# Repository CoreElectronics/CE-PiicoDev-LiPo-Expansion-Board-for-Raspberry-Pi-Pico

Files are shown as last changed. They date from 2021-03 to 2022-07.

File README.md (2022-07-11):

# PiicoDev® LiPo Expansion Board for Raspberry Pi Pico

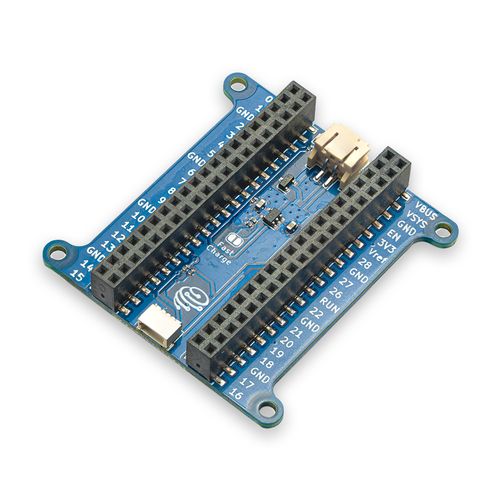
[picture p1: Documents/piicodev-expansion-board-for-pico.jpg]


The [PiicoDev® LiPo Expansion Board for Raspberry Pi Pico](https://core-electronics.com.au/catalog/product/view/sku/CE07693) is a great way to start experimenting with Raspberry Pi Pico/RP2040. Thanks to the onboard PiicoDev connector, you can quickly and easily connect to the PiicoDev family of sensor modules without soldering.

- Breaks out each Pico pin, with handy labels
- Take your project on the go with on-board LiPo battery charging.
- PiicoDev connector, compatible with Qwiic and STEMMA QT (3.3V only)
- Manufactured and [supported](https://core-electronics.com.au/contacts/) in Australia by Core Electronics

**Technical Details**

- Dimensions: 51x51mm
- M2.5 mounting holes
- Charge current: approx 220mA / 440mA (when Fast Charge jumper is soldered)
- PiicoDev connector: I2C0 (SCL:Pin 9, SDA:Pin 8)
- PiicoDev connector pinout:
  - 1 GND
  - 2 3.3V
  - 3 SDA
  - 4 SCL
- The I2C Bus presented at the PiicoDev connector contains series 120Ohm resistances to prevent destructive signal undershoot. Refer to the [schematic](Documents/schematic.pdf) for more information. To operate without these series resistors, users may connect directly to the GPIO instead.

# License
This project is open source - please review the LICENSE.md file for further licensing information.

If you have any technical questions, or concerns about licensing, please contact technical support on the [Core Electronics forums](https://forum.core-electronics.com.au/).

---
*\"PiicoDev" is a registered trademark of Core Electronics Pty Ltd*

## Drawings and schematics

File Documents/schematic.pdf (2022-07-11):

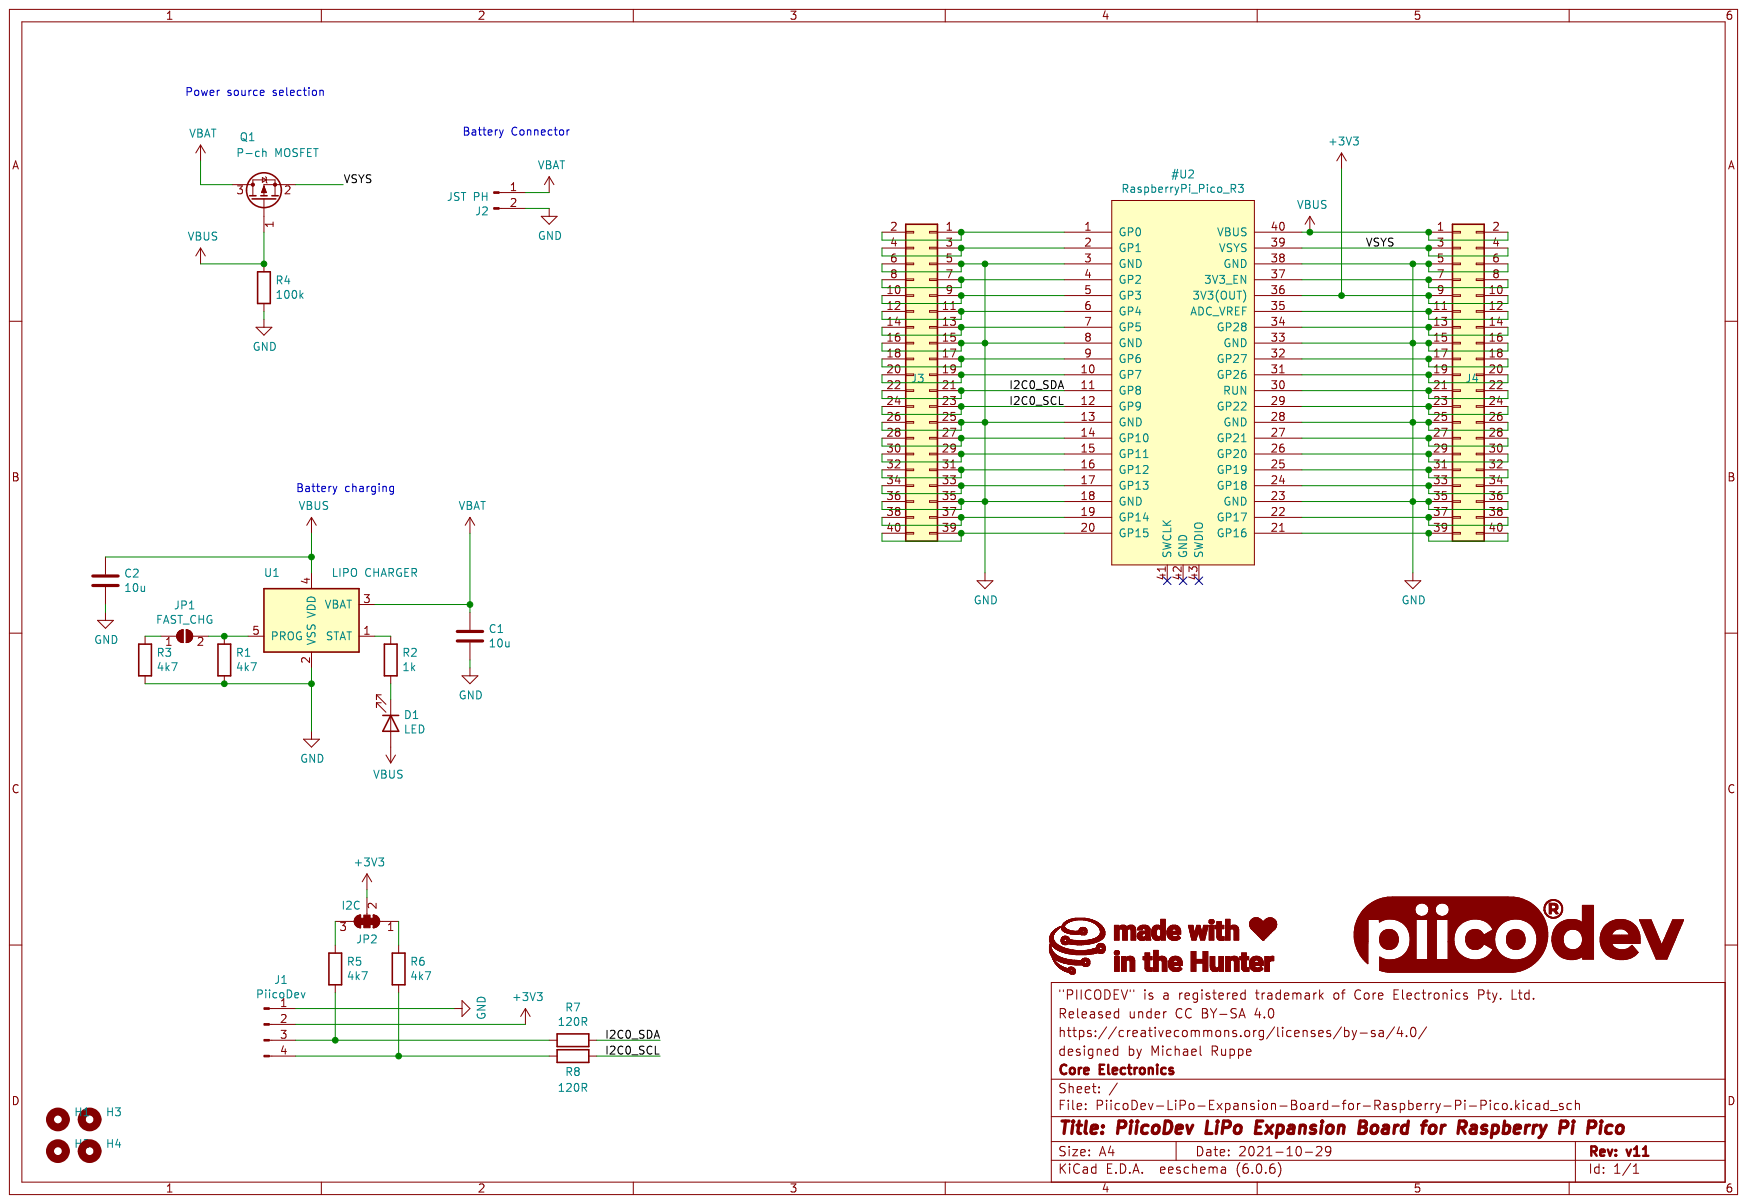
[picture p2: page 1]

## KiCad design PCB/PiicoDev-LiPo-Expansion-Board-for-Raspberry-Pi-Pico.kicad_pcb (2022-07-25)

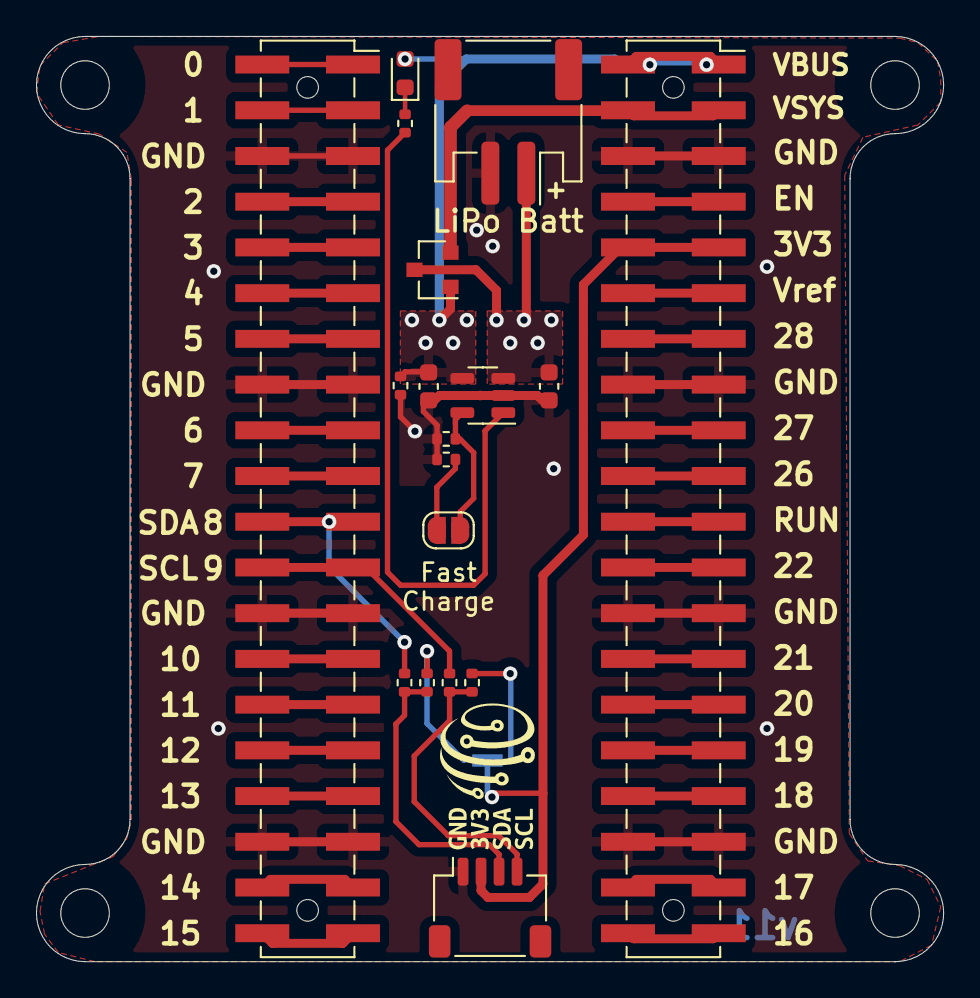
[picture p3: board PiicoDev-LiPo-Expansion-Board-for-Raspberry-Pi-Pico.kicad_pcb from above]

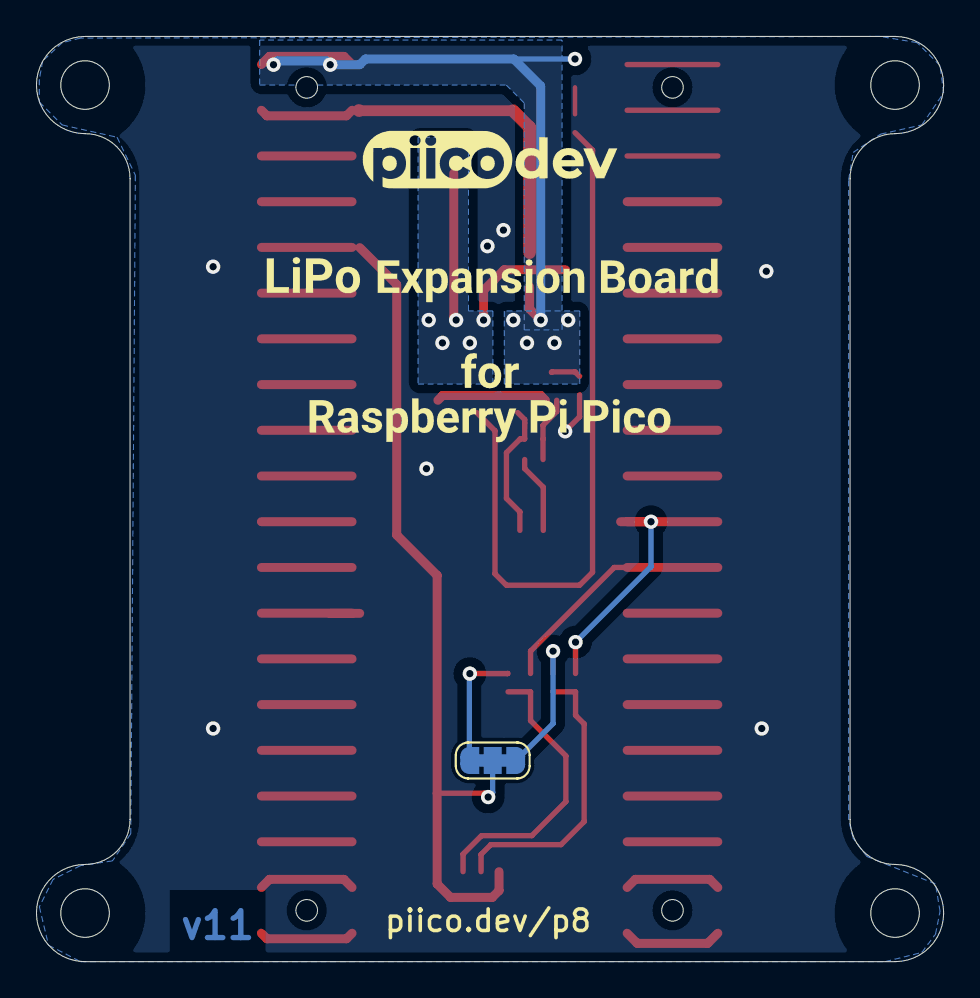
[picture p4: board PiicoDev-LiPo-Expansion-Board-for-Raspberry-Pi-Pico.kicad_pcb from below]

Board: 2 copper layers, 50.4 x 51.4 mm, 33 parts (6 on the bottom side), 42 nets.

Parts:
C1, C2: 10u; C_0603_1608Metric
D1: LED; LED_0603_1608Metric
G1: LOGO_CoreElectronics_made-with-love; CoreElectronics_logo_5mm
G2: LOGO_PiicoDev; piicodev_logo_14.2x3.4mm
H1, H2, H3, H4: MountingHole_2.7mm_M2.5
J1: PiicoDev; JST_SH_SM04B-SRSS-TB_1x04-1MP_P1.00mm_Horizontal
J2: JST PH; JST_PH_S2B-PH-SM4-TB_1x02-1MP_P2.00mm_Horizontal
J3, J4: PinSocket_2x20_P2.54mm_Vertical_SMD_With_Post
JP1: FAST_CHG; SolderJumper-2_P1.3mm_Open_RoundedPad1.0x1.5mm
JP2: I2C; SolderJumper-3_P1.3mm_Closed_RoundedPad1.0x1.5mm
Q1: DMG3415U-7; SOT-23
R1, R2, R3, R5, R6: 4k7; R_0402_1005Metric
R4: 100k; R_0402_1005Metric
R7, R8: 120R; R_0402_1005Metric
U1: MCP73832-2-OT; SOT-23-5
kibuzzard-62DE0FE6: G***; kibuzzard-62DE0FE6
kibuzzard-629D8D5D: G***; kibuzzard-629D8D5D
kibuzzard-629D8D6F: G***; kibuzzard-629D8D6F
kibuzzard-629D8D51: G***; kibuzzard-629D8D51
kibuzzard-629D8D64: G***; kibuzzard-629D8D64
kibuzzard-629D90AA: G***; kibuzzard-629D90AA
kibuzzard-629D909F: G***; kibuzzard-629D909F
kibuzzard-629D9090: G***; kibuzzard-629D9090

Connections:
+3V3: J1.2, J4.9, J4.10, JP2.2
/I2C0_SCL: J3.23, J3.24, R8.1
/I2C0_SDA: J3.21, J3.22, R7.1
/VSYS: J4.3, J4.4, Q1.2
GND: C1.2, C2.2, J1.1, J2.2, J3.5, J3.6, J3.15, J3.16, J3.25, J3.26, J3.35, J3.36, J4.5, J4.6, J4.15, J4.16, J4.25, J4.26, J4.35, J4.36, R1.2, R3.2, R4.2, U1.2
unnamed: D1.1, R2.2
unnamed: J1.3, R5.2, R7.2
unnamed: J1.4, R6.2, R8.2
unnamed: J3.1, J3.2
unnamed: J3.3, J3.4
unnamed: J3.7, J3.8
unnamed: J3.9, J3.10
unnamed: J3.11, J3.12
unnamed: J3.13, J3.14
unnamed: J3.17, J3.18
unnamed: J3.19, J3.20
unnamed: J3.27, J3.28
unnamed: J3.29, J3.30
unnamed: J3.31, J3.32
unnamed: J3.33, J3.34
unnamed: J3.37, J3.38
unnamed: J3.39, J3.40
unnamed: J4.7, J4.8
unnamed: J4.11, J4.12
unnamed: J4.13, J4.14
unnamed: J4.17, J4.18
unnamed: J4.19, J4.20
unnamed: J4.21, J4.22
unnamed: J4.23, J4.24
unnamed: J4.27, J4.28
unnamed: J4.29, J4.30
unnamed: J4.31, J4.32
unnamed: J4.33, J4.34
unnamed: J4.37, J4.38
unnamed: J4.39, J4.40
unnamed: JP1.1, R3.1
unnamed: JP1.2, R1.1, U1.5
unnamed: JP2.1, R6.1
unnamed: JP2.3, R5.1
unnamed: R2.1, U1.1
VBAT: C1.1, J2.1, Q1.3, U1.3
VBUS: C2.1, D1.2, J4.1, J4.2, Q1.1, R4.1, U1.4

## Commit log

2021-04-25 Add datasheet for the charge IC
    Add datasheet for the charge IC
2021-10-28 Update links and silk text
    [PiicoDev-Expansion-Board-for-Raspberry-Pi-Pico.kicad_pcb]
2021-10-29 Add 120R to SCL & SDA. Improve silk screen.
    [PiicoDev-Expansion-Board-for-Raspberry-Pi-Pico.kicad_pcb, PiicoDev-Expansion-Board-for-Raspberry-Pi-Pico.sch]
2021-12-30 Change LED Resistor from 1k to 4.7k
    [PiicoDev-Expansion-Board-for-Raspberry-Pi-Pico.kicad_pcb, PiicoDev-Expansion-Board-for-Raspberry-Pi-Pico.sch]
2022-02-24 Update schematic pdf to v11
    [PiicoDev-Expansion-Board-for-Raspberry-Pi-Pico.sch]
2022-07-11 Update project to KiCad v6
    [PiicoDev-Expansion-Board-for-Raspberry-Pi-Pico.kicad_sch, PiicoDev-Expansion-Board-for-Raspberry-Pi-Pico.sch]
2022-07-11 Rename project to '... LiPo Expansion...'
    [PiicoDev-Expansion-Board-for-Raspberry-Pi-Pico.sch, PiicoDev-LiPo-Expansion-Board-for-Raspberry-Pi-Pico.kicad_pcb, PiicoDev-LiPo-Expansion-Board-for-Raspberry-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]
2022-07-11 update schematic title block
    [PiicoDev-LiPo-Expansion-Board-for-Raspberry-Pi-Pico.kicad_sch]
2022-07-25 update artwork for 'LiPo' expansion
    [PiicoDev-LiPo-Expansion-Board-for-Raspberry-Pi-Pico.kicad_pcb]

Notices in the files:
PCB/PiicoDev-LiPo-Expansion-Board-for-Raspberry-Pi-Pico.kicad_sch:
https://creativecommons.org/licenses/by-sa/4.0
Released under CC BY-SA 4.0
